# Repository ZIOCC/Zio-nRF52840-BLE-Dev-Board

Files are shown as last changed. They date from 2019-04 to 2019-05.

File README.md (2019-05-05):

## Zio nRF52840 BLE Dev Board

> This board is available for purchase [here](https://www.smart-prototyping.com/Zio-Qwiic-nrf52840-Dev-Board)

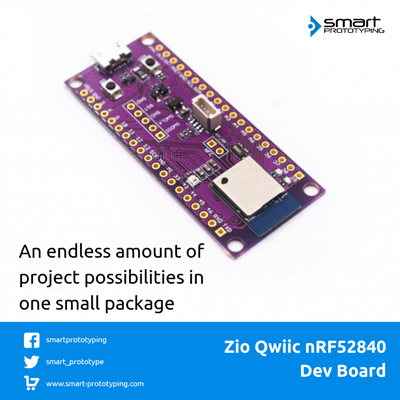
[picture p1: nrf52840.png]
nRF52840 Board


This is a development and breakout board based on nRF52840 SoC - a powerful combination of ARM Cortex-M4 CPU and 2.4GHz Bluetooth radio. With the nRF52840 at the heart of your project, you’ll be presented with a seemingly endless list of project-possibilities in an incredibly small package.

This board breaks out most of the nRF52840 module’s pins, including GPIO, UART, SPI, I2C, NFC, etc.. With the Micro USB connector, you can easily program and supply power to it. We’ve flashed [Adafruit’s nrf52 bootloader](https://github.com/adafruit/Adafruit_nRF52_Bootloader), an Arduino core for our nRF board, so you can interface with the arduino IDE. 

Additionally, we put a Qwiic connector on the board, so you can easily use our Qwiic modules with this development board. And there is a [full-color addressable LED WS2812-2020](https://www.smart-prototyping.com/WS2812-2020-Addressable-Fullcolor-RGB-LED) connected to Pin8. We also break out the NFC pins for NFC testing purpose. 

It also support programming with CircuitPython, check sparkfun’s tutorial [here](https://learn.sparkfun.com/tutorials/sparkfun-pro-nrf52840-mini-hookup-guide). 

You can find most of the technical specifications details from the [nRF52840 module datasheet](https://github.com/ZIOCC/Zio-nRF52840-BLE-Dev-Board/blob/master/MDBT50Q-P.pdf). 

**Other Specifications**

* Dimension: 57.4 x 23.9mm
* Weight: 5.1g
* Operation Voltage: 3.3V

**Links**

* [PCB schematic](https://github.com/ZIOCC/Zio-nRF52840-BLE-Dev-Board/blob/master/zio%20nRF52840%20BLE%20Dev%20Board.pdf)
* [PCB Source File](https://github.com/ZIOCC/Zio-nRF52840-BLE-Dev-Board/tree/master/EAGLE)
* [Datasheet](https://github.com/ZIOCC/Zio-nRF52840-BLE-Dev-Board/blob/master/MDBT50Q-P.pdf) 
* [Nordic nRF5 SDK](https://www.nordicsemi.com/eng/Products/Bluetooth-low-energy/nRF5-SDK) 
* [Bootloader Source Code](https://github.com/adafruit/Adafruit_nRF52_Bootloader)
* [Adafruit Arduino IDE tutorial](https://learn.adafruit.com/introducing-the-adafruit-nrf52840-feather)
* [Sparkfun CircuitPython tutorial](https://learn.sparkfun.com/tutorials/sparkfun-pro-nrf52840-mini-hookup-guide)
* [Pins definition](https://www.smart-prototyping.com/image/data/NOA-RnD/101968%20nrf52840%20dev%20board/nRF52840_variant.h)
* [GitHub](https://github.com/ZIOCC/Zio-nRF52840-BLE-Dev-Board)

###### About Zio
> Zio is a new line of open sourced, compact, and grid layout boards, fully integrated for Arduino and Qwiic ecosystem. Designed ideally for wearables, robotics, small-space limitations or other on the go projects. Check out other awesome Zio products [here](https://www.smart-prototyping.com/Zio).

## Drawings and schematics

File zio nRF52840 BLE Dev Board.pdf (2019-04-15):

# GND GND

L1 | C¹³R7 | D2 | GND

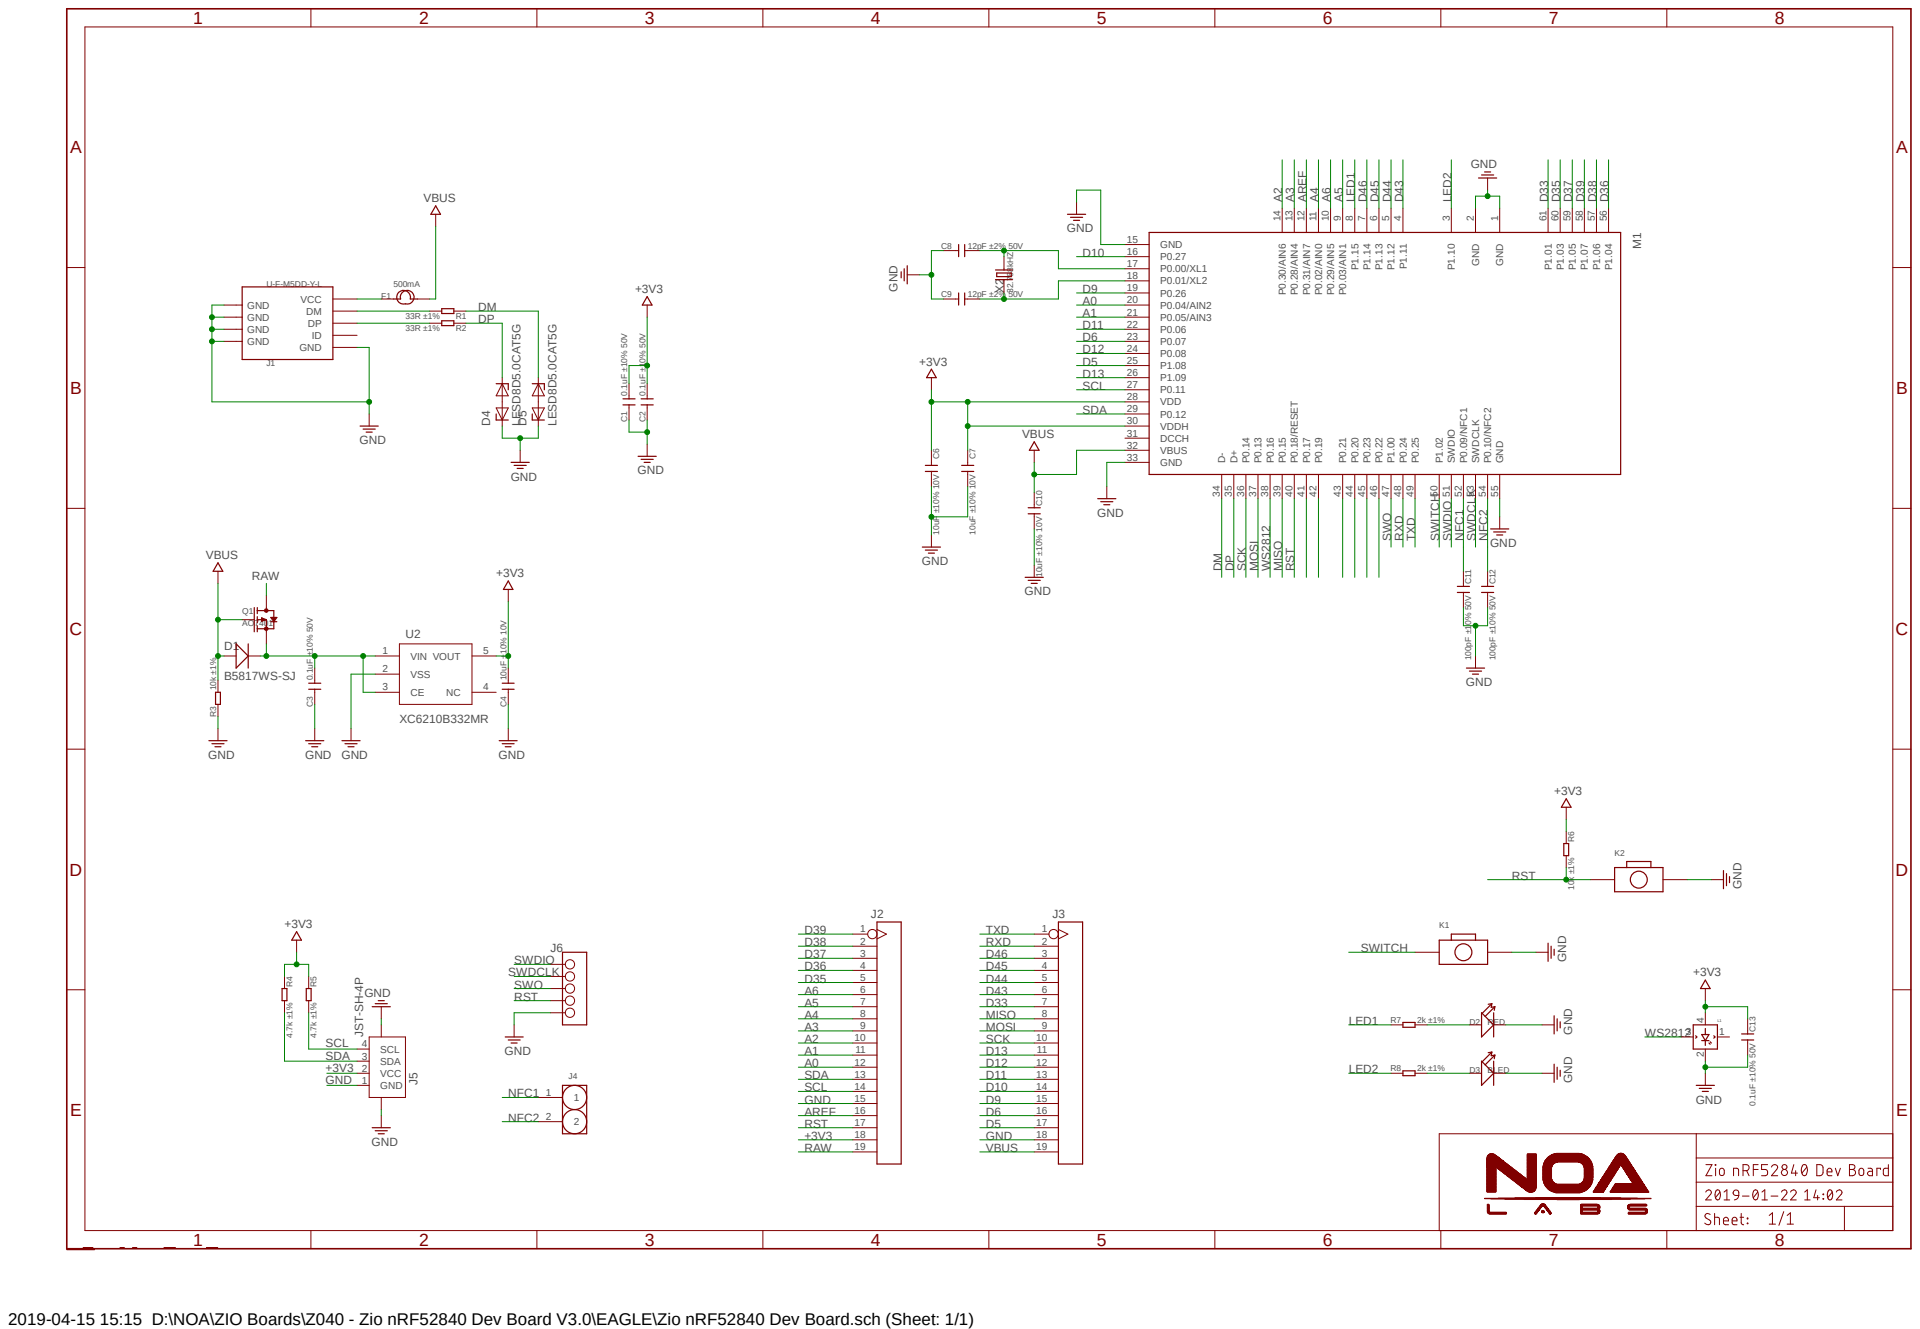
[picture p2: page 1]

VCC GND GND GND GND

2019-04-15 15:15 D:\NOA\ZIO Boards\Z040 - Zio nRF52840 Dev Board V3.0\EAGLE\Zio nRF52840 Dev Board.sch (Sheet: 1/1)

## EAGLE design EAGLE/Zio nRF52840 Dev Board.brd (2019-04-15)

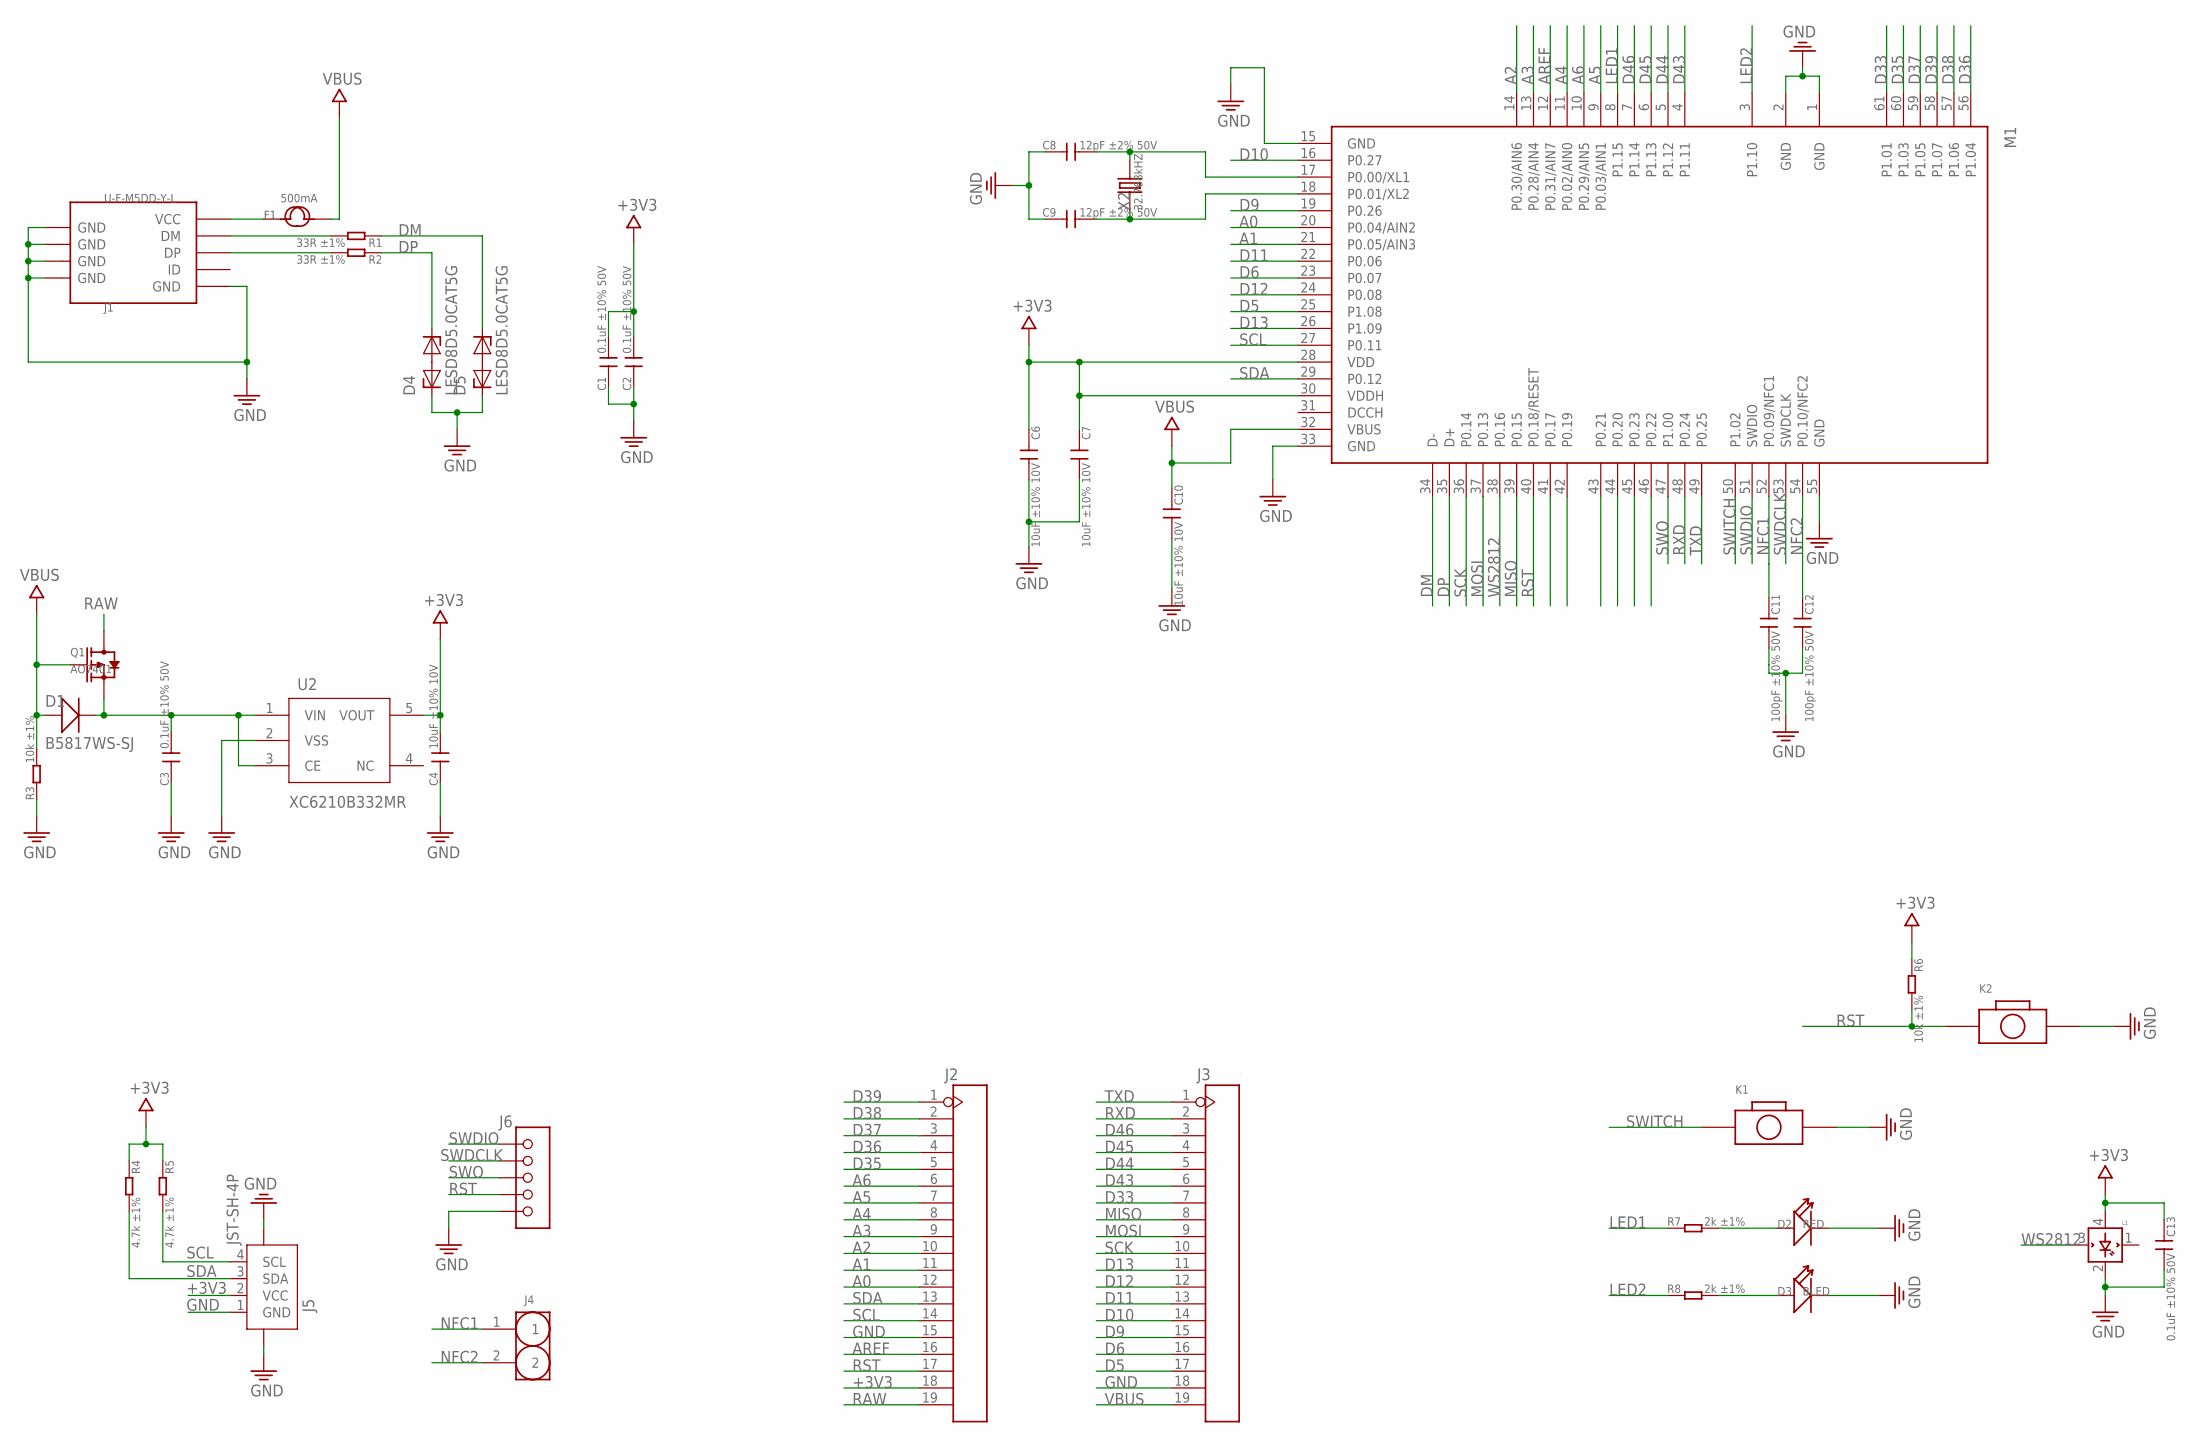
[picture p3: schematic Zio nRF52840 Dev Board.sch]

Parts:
C1, C2, C3, C13: 0.1uF ±10% 50V; C0402
C4, C6, C7, C10: 10uF ±10% 10V; C0603
C8, C9: 12pF ±2% 50V; C0402
C11, C12: 100pF ±10% 50V; C0402
D1: B5817WS-SJ; SOD323
D2: RED; LED-0603
D3: BLED; LED-0603
D4, D5: LESD8D5.0CAT5G; SOD882
F1: 500mA; 1206
J1: U-F-M5DD-Y-L; MICRO-SMD
J2, J3: HEADER-19P; 19P-2.54
J4: HEADER-2P-65/35MIL; 2P-2.54-65/35MIL
J5: JST-SH-4P; JST-SH-4P-90
J6: HEADER-5P-2.54; 5P-2.54
K1, K2: BOTTON-2PSKRKAEE020; SKRKAEE020
L1: WS2812B2020; WS2812_2020
M1: MDBT50
Q1: AO7401; SOT-323
R1, R2: 33R ±1%; R0402
R3, R6: 10k ±1%; R0402
R4, R5: 4.7k ±1%; R0402
R7, R8: 2k ±1%; R0402
U2: XC6210B332MR; SOT23-5
X2: 32.768kHZ; 2P-SMD-3.2X1.5

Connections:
+3V3: C1.2, C2.2, C4.2, C6.1, C7.1, C13.1, J2.18, J5.2 (VCC), L1.4 (VDD), M1.28 (VDD), M1.30 (VDDH), R4.1, R5.1, R6.1, U2.5 (VOUT)
A0: J2.12, M1.20 (P0.04/AIN2)
A1: J2.11, M1.21 (P0.05/AIN3)
A2: J2.10, M1.14 (P0.30/AIN6)
A3: J2.9, M1.13 (P0.28/AIN4)
A4: J2.8, M1.11 (P0.02/AIN0)
A5: J2.7, M1.9 (P0.03/AIN1)
A6: J2.6, M1.10 (P0.29/AIN5)
AREF: J2.16, M1.12 (P0.31/AIN7)
D5: J3.17, M1.25 (P1.08)
D6: J3.16, M1.23 (P0.07)
D9: J3.15, M1.19 (P0.26)
D10: J3.14, M1.16 (P0.27)
D11: J3.13, M1.22 (P0.06)
D12: J3.12, M1.24 (P0.08)
D13: J3.11, M1.26 (P1.09)
D33: J3.7, M1.61 (P1.01)
D35: J2.5, M1.60 (P1.03)
D36: J2.4, M1.56 (P1.04)
D37: J2.3, M1.59 (P1.05)
D38: J2.2, M1.57 (P1.06)
D39: J2.1, M1.58 (P1.07)
D43: J3.6, M1.4 (P1.11)
D44: J3.5, M1.5 (P1.12)
D45: J3.4, M1.6 (P1.13)
D46: J3.3, M1.7 (P1.14)
DM: D5.2, M1.34 (D-), R1.1
DP: D4.2, M1.35 (D+), R2.1
GND: C1.1, C2.1, C3.1, C4.1, C6.2, C7.2, C8.1, C9.1, C10.2, C11.2, C12.2, C13.2, D2.-, D3.-, D4.1, D5.1, J1.P5 (GND), J1.S1 (GND), J1.S2 (GND), J1.S3 (GND), J1.S4 (GND), J2.15, J3.18, J5.1 (GND), J5.5, J5.6, J6.5, K1.2, K2.2, L1.2 (GND), M1.1 (GND), M1.2 (GND), M1.15 (GND), M1.33 (GND), M1.55 (GND), R3.1, U2.2 (VSS)
LED1: M1.8 (P1.15), R7.1
LED2: M1.3 (P1.10), R8.1
MISO: J3.8, M1.39 (P0.15)
MOSI: J3.9, M1.37 (P0.13)
unnamed: D3.+, R8.2
unnamed: J1.P2 (DM), R1.2
unnamed: D2.+, R7.2
unnamed: C8.2, M1.17 (P0.00/XL1), X2.2
unnamed: F1.1, J1.P1 (VCC)
unnamed: J1.P3 (DP), R2.2
unnamed: C9.2, M1.18 (P0.01/XL2), X2.1
NFC1: C11.1, J4.1, M1.52 (P0.09/NFC1)
NFC2: C12.1, J4.2, M1.54 (P0.10/NFC2)
QSPI_CS: M1.44 (P0.20)
QSPI_DATA0: M1.41 (P0.17)
QSPI_DATA1: M1.46 (P0.22)
QSPI_DATA2: M1.45 (P0.23)
QSPI_DATA3: M1.43 (P0.21)
QSPI_SCK: M1.42 (P0.19)
RAW: J2.19, Q1.3 (D)
RST: J2.17, J6.4, K2.1, M1.40 (P0.18/RESET), R6.2
RXD: J3.2, M1.48 (P0.24)
SCK: J3.10, M1.36 (P0.14)
SCL: J2.14, J5.4 (SCL), M1.27 (P0.11), R5.2
SDA: J2.13, J5.3 (SDA), M1.29 (P0.12), R4.2
SWDCLK: J6.2, M1.53 (SWDCLK)
SWDIO: J6.1, M1.51 (SWDIO)
SWITCH: K1.1, M1.50 (P1.02)
SWO: J6.3, M1.47 (P1.00)
TXD: J3.1, M1.49 (P0.25)
VBUS: C10.1, D1.+, F1.2, J3.19, M1.32 (VBUS), Q1.1 (G), R3.2
VIN: C3.2, D1.-, Q1.2 (S), U2.1 (VIN), U2.3 (CE)
WS2812: L1.3 (DIN), M1.38 (P0.16)

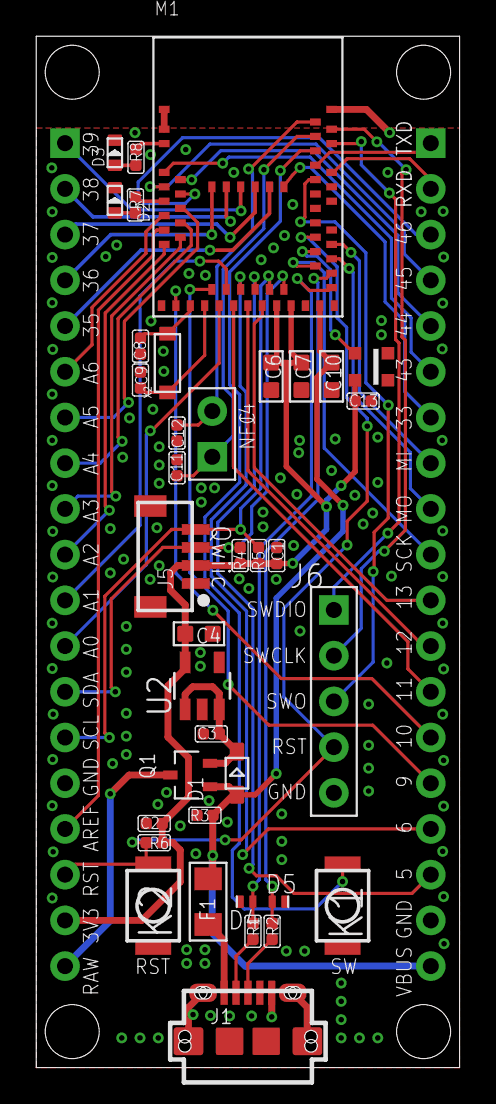
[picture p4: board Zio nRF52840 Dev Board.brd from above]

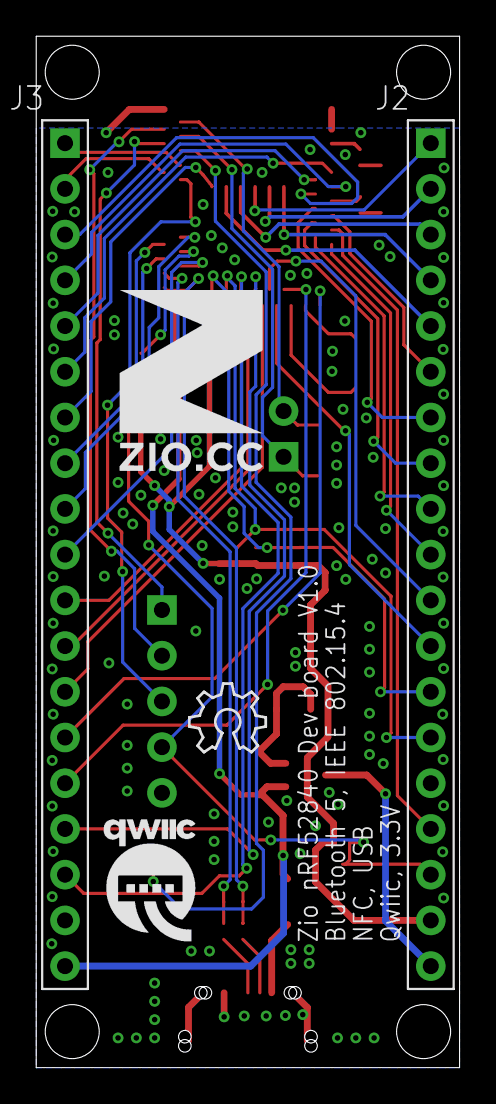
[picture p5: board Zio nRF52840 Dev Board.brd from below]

Board: 2 copper layers, 23.5 x 57.3 mm, 42 parts (5 on the bottom side), 56 nets.

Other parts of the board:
U$17: 10MM
U$18: QWIIC-LOGO-MEDIUM
U$19: OSHW_6X150_NOTEXT
